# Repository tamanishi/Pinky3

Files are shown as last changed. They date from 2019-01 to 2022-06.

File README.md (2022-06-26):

# Pinky3

> **Warning**  
> If you are using Kicad 6, please see https://github.com/tamanishi/Pinky4/issues/4 .

A split 3 x 7 vertically staggered keys and 4 thumb keys keyboard.  
An idea is inspired from [crkbd](https://github.com/foostan/crkbd), [Lily58](https://github.com/kata0510/Lily58), [Ergo42](https://github.com/Biacco42/Ergo42) and [Helix](https://github.com/MakotoKurauchi/helix).  

product

## Pcb & Plates

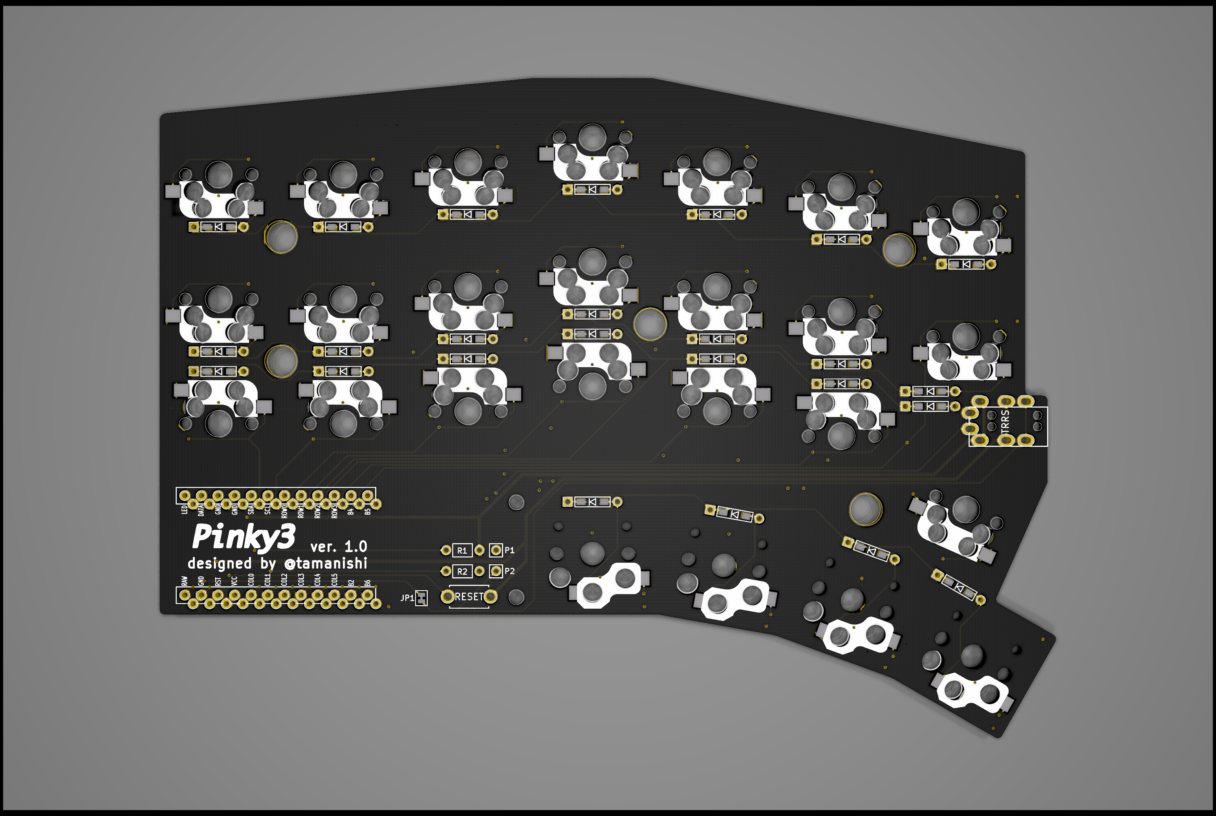
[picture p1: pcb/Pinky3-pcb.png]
pcb

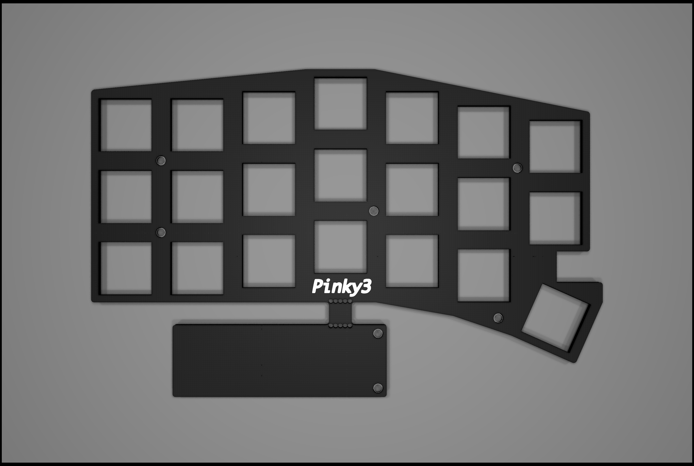
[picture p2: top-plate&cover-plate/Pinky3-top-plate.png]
top plate

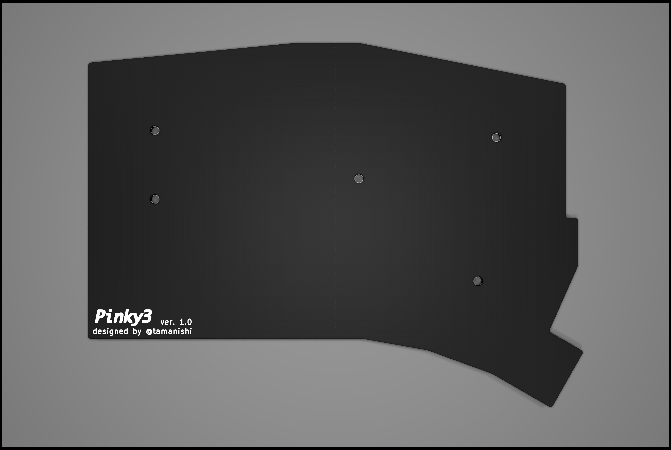
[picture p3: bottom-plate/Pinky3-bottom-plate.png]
bottom plate

<!-- ![plates](plates/Pinky3-plates.png) -->

## Bill of Materials (for both hands)

| # | name | qty |
| ---: | :--- | ---: |
| 1 | pcbs | 2 |
| 2 | top plates | 2 |
| 3 | bottom plates | 2 |
| 4 | Pro Micros | 2 |
| 5 | Conthrough for Pro Micros | 4 |
| 6 | 2 pins tact switches | 2 |
| 7 | TRRS connectors | 2 |
| 8 | diodes (1N4148 or 1N4148W) | 50 |
| 9 | Kailh PCB Sockets (MX Sockets) | 42 |
| 10 | Kailh PCB Sockets (Choc Sockets) | 8 |
| 11 | Cherry MX compatible keyswitches | 42 |
| 12 | Kailh low profile (Choc) keyswitches | 8 |
| 13 | Cherry MX compatible keycaps | 42 |
| 14 | Kailh low profile (Choc) compatible keycaps | 8 |
| 15 | TRS or TRRS cable | 1 |
| 16 | 7mm M2 standoffs (for top and bottom plates) | 10 |
| 17 | 5.5mm M2 standoffs (for Pro Micro cover plates) | 4 |
| 18 | 4mm M2 screws | 28 |
| 19 | rubber cushions | 8 |

## Firmware

See [Quantum Mechanical Keyboard Firmware](https://qmk.fm) and [its Pinky support page](https://github.com/qmk/qmk_firmware/blob/master/keyboards/pinky/readme.md)

## TODOs

- [x] add images (finished product, pcb, plates and parts?)
- [x] add BOM
- [ ] add build log

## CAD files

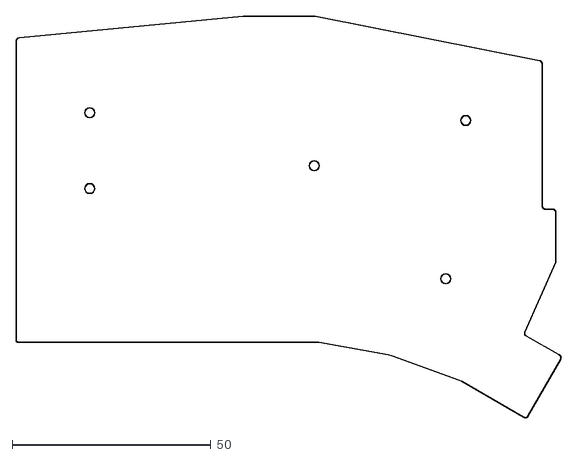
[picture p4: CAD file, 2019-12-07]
bottom-plate-dxf/DXF/Pinky3-bottom-plate-dxf-Edge_Cuts.dxf
137.0 x 100.9

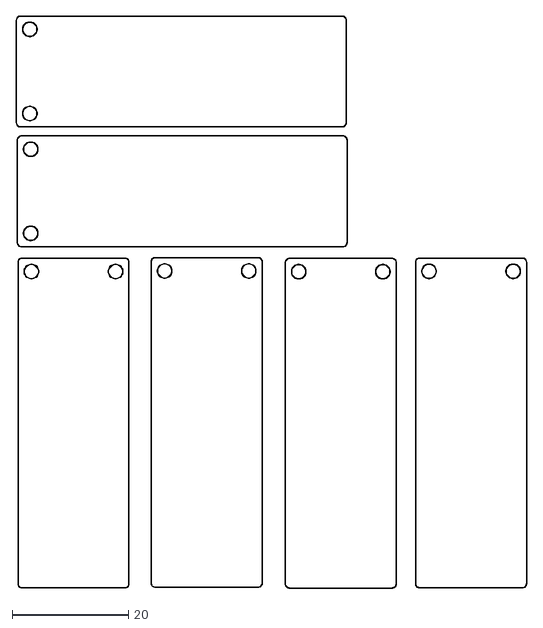
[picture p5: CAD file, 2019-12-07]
cover-plate/DXF/Pinky3-cover-plate-Edge_Cuts.dxf
87.9 x 98.5

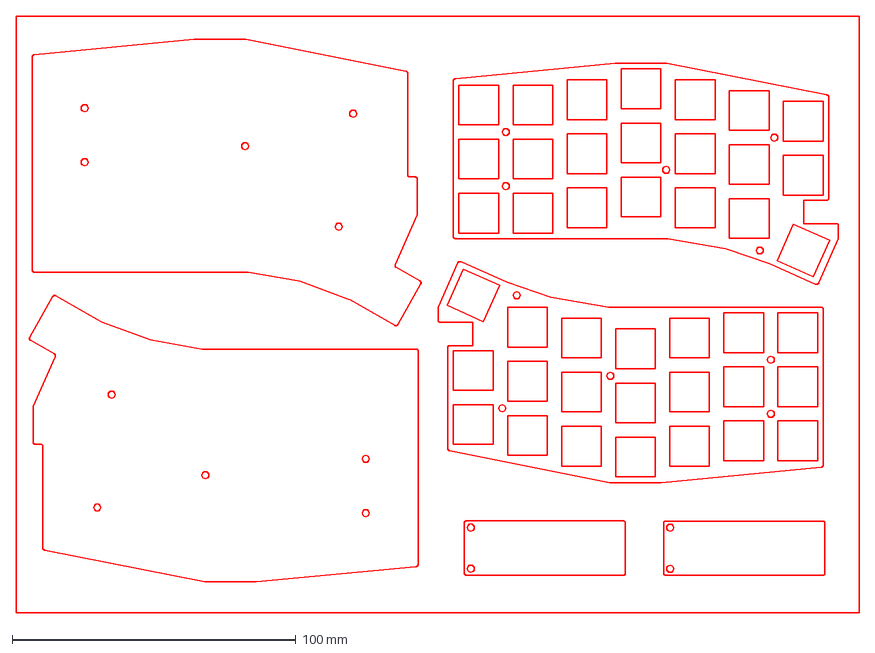
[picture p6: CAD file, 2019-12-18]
plates/DXF/Pinky3_Acrylic_Plates.dxf
297.0 x 210.0 mm

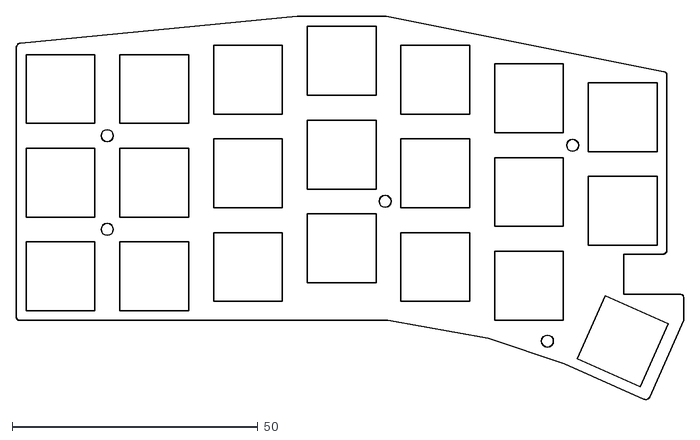
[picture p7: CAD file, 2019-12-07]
top-plate-only-dxf/DXF/Pinky3-top-plate-dxf-Edge_Cuts.dxf
135.7 x 77.9

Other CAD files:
bottom-plate-dxf/DXF/Pinky3-bottom-plate-dxf-Edge_Cuts.dwg
cover-plate/DXF/Pinky3-cover-plate-Edge_Cuts.dwg
plates/DXF/Pinky3_Acrylic_Plates.dwg
top-plate-only-dxf/DXF/Pinky3-top-plate-dxf-Edge_Cuts.dwg

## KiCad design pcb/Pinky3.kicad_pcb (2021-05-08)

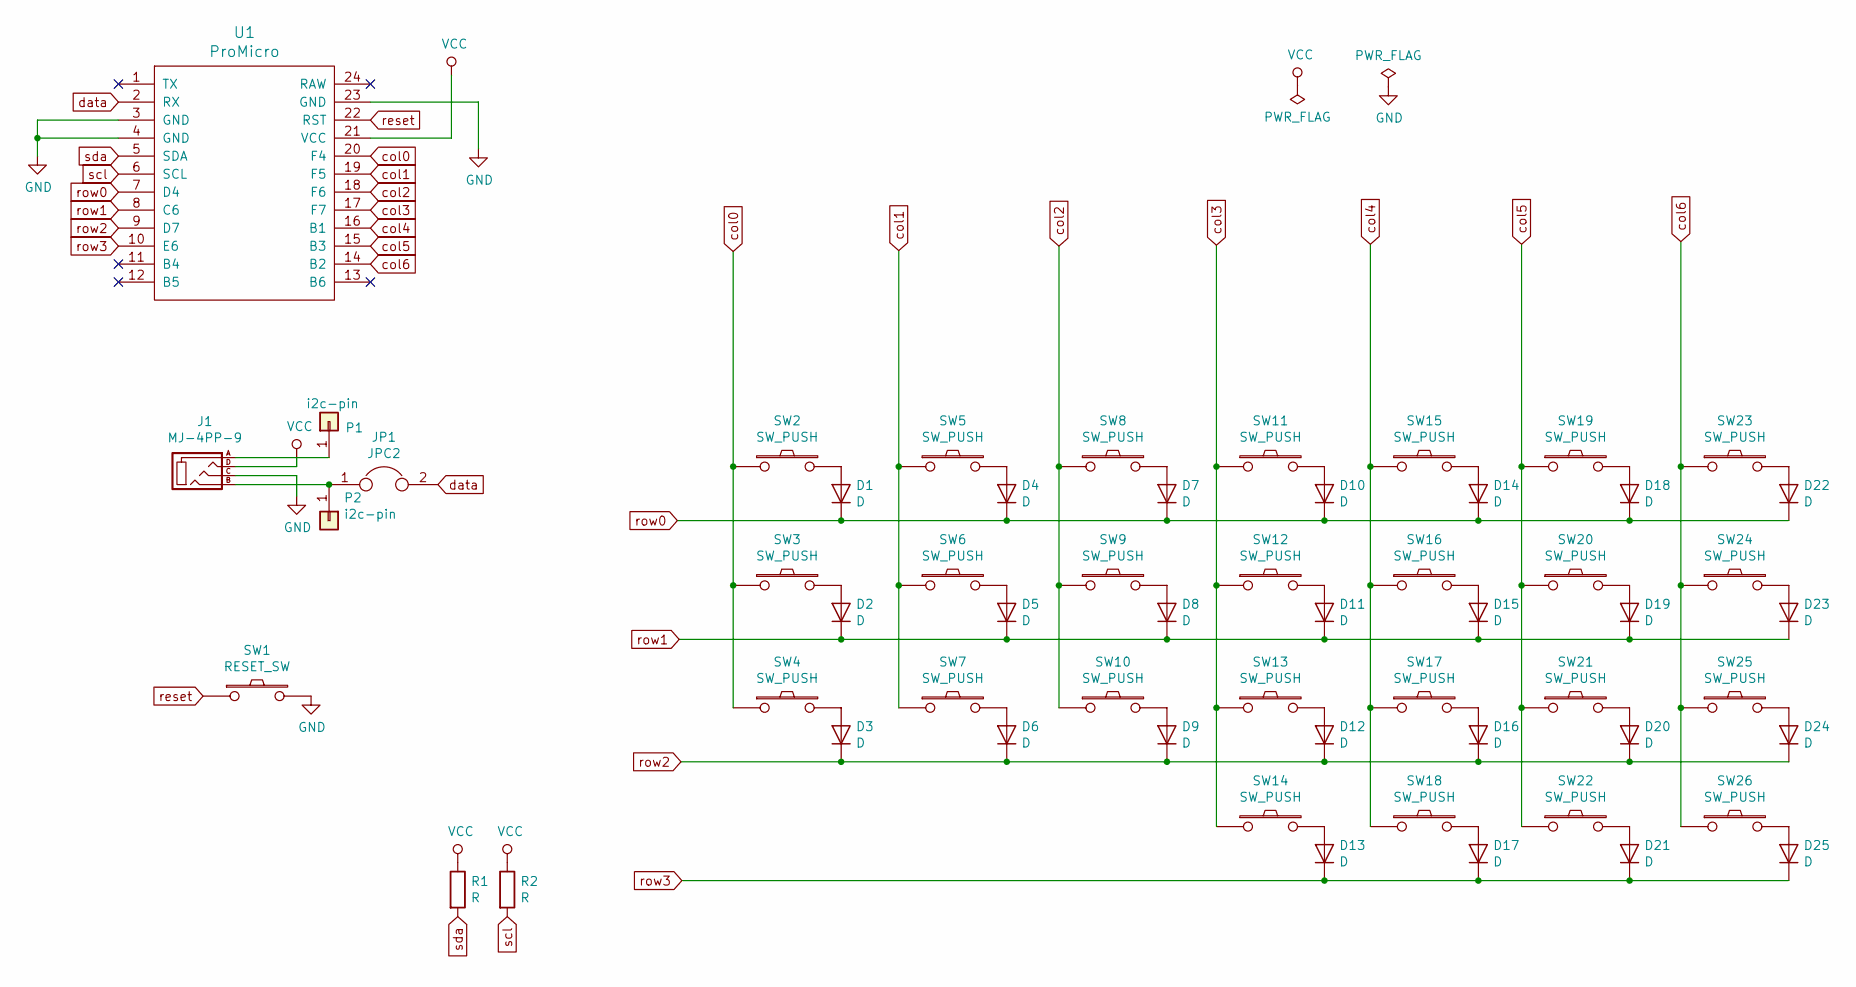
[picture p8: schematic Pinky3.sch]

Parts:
D1, D2, D3, D4, D5, D6, D7, D8, D9, D10, D11, D12, D13, D14, D15, D16, D17, D18, D19, D20, D21, D22, D23, D24, D25: D; D3_TH_SMD
J1: MJ-4PP-9
JP1: JPC2
P1, P2: i2c-pin; 1pin_conn
R1, R2: R
SW1: RESET_SW; ResetSW
SW2, SW3, SW4, SW5, SW6, SW7, SW8, SW9, SW10, SW11, SW12, SW13, SW15, SW16, SW17, SW19, SW20, SW21, SW23, SW24, SW25: SW_PUSH; CherryMX_Hotswap
SW14, SW18, SW22, SW26: SW_PUSH; Choc_Hotswap
U1: ProMicro; ProMicro_v2

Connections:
GND: J1.C, SW1.2, U1.3 (GND), U1.4 (GND), U1.23 (GND)
unnamed: D1.2 (A), SW2.2
unnamed: D2.2 (A), SW3.2
unnamed: D3.2 (A), SW4.2
unnamed: D4.2 (A), SW5.2
unnamed: D5.2 (A), SW6.2
unnamed: D6.2 (A), SW7.2
unnamed: D7.2 (A), SW8.2
unnamed: D8.2 (A), SW9.2
unnamed: D9.2 (A), SW10.2
unnamed: D10.2 (A), SW11.2
unnamed: D11.2 (A), SW12.2
unnamed: D12.2 (A), SW13.2
unnamed: D13.2 (A), SW14.2
unnamed: D14.2 (A), SW15.2
unnamed: D15.2 (A), SW16.2
unnamed: D16.2 (A), SW17.2
unnamed: D17.2 (A), SW18.2
unnamed: D18.2 (A), SW19.2
unnamed: D19.2 (A), SW20.2
unnamed: D20.2 (A), SW21.2
unnamed: D21.2 (A), SW22.2
unnamed: D22.2 (A), SW23.2
unnamed: D23.2 (A), SW24.2
unnamed: D24.2 (A), SW25.2
unnamed: D25.2 (A), SW26.2
unnamed: J1.B, JP1.1, P2.1
col0: SW2.1, SW3.1, SW4.1, U1.20 (F4)
col1: SW5.1, SW6.1, SW7.1, U1.19 (F5)
col2: SW8.1, SW9.1, SW10.1, U1.18 (F6)
col3: SW11.1, SW12.1, SW13.1, SW14.1, U1.17 (F7)
col4: SW15.1, SW16.1, SW17.1, SW18.1, U1.16 (B1)
col5: SW19.1, SW20.1, SW21.1, SW22.1, U1.15 (B3)
col6: SW23.1, SW24.1, SW25.1, SW26.1, U1.14 (B2)
data: JP1.2, U1.2 (RX)
reset: SW1.1, U1.22 (RST)
row0: D1.1 (K), D4.1 (K), D7.1 (K), D10.1 (K), D14.1 (K), D18.1 (K), D22.1 (K), U1.7 (D4)
row1: D2.1 (K), D5.1 (K), D8.1 (K), D11.1 (K), D15.1 (K), D19.1 (K), D23.1 (K), U1.8 (C6)
row2: D3.1 (K), D6.1 (K), D9.1 (K), D12.1 (K), D16.1 (K), D20.1 (K), D24.1 (K), U1.9 (D7)
row3: D13.1 (K), D17.1 (K), D21.1 (K), D25.1 (K), U1.10 (E6)
scl: R2.2, U1.6 (SCL)
sda: R1.2, U1.5 (SDA)

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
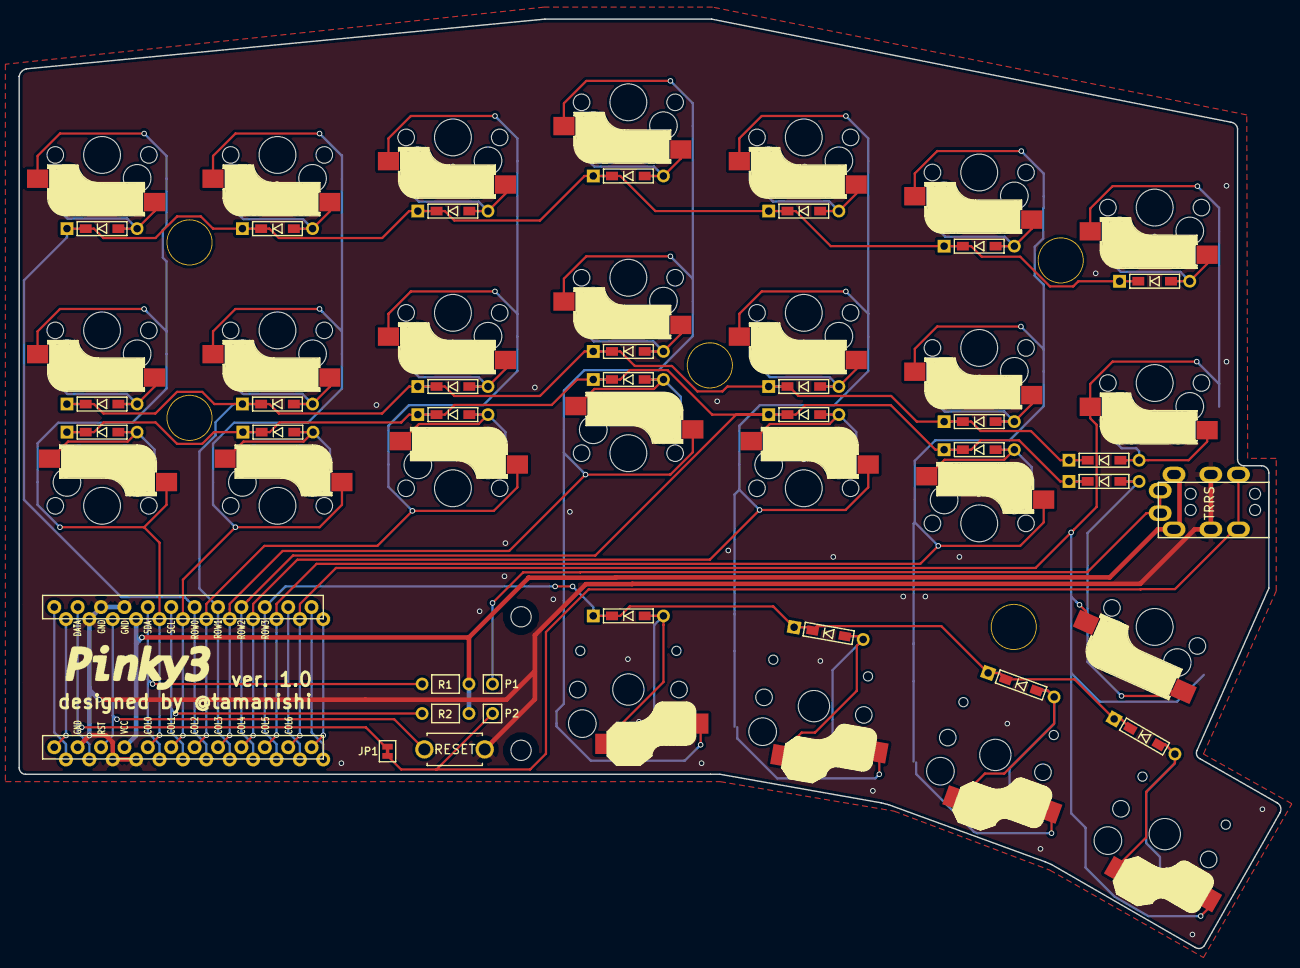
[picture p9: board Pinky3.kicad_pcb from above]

Board: 2 copper layers, 137.0 x 100.9 mm, 65 parts (0 on the bottom side), 44 nets.

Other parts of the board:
HOLE_M2, HOLE_M2#2: VAL**; HOLE_M2
Ref**: Val**; HOLE
Ref**#2, Ref**#3, Ref**#4, Ref**#5: Val**; HOLE

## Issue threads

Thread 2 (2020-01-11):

[question] What are JP1, R1, R2, P1, and P2 for?

repercussion, 2020-01-11:
JP1 - What is this jumper for?

R1 and R2 - I assume these are for resistors for underglow?

P1 and P2 - Haven't the foggiest.

tamanishi, 2020-01-14:
[image: reset_switch.jpg]
Hi.

Sorry for the late reply.

> I've bought a few PCBs and necessary parts, but I'm wondering if you
might help me find the appropriate resest switches.

I'm using reset switch like this. (see attached.

> JP1 - What is this jumper for?

> R1 and R2 - I assume these are for resistors for underglow?

> P1 and P2 - Haven't the foggiest.
JP1 is for switching the communication protocol for left and right between
I2C or serial.
If JP1 is closed, the communication is on serial protocol.
If JP1 is opened, the communication is on I2C protocol.
and R1, R2, P1 and P2 are for I2C protocol.
But I don't test I2C protocol physically yet.

Serial protocol is OK for me for now.

I hope this helps you.

--
Masayuki Sunahara

On Sun, Jan 12, 2020 at 5:02 AM repercussion <notifications@github.com>
wrote:

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

repercussion, 2020-01-15:
Thank you very much for the information!

The image of the reset switch didn't make it from attachment to GitHub.

tamanishi, 2020-01-15:
Oops.

please try this.

https://imgur.com/gallery/vSJpcNz

--
Masayuki Sunahara

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

repercussion, 2020-01-21:
Thanks!

[Reset switch](https://i.imgur.com/EkxfLI0.jpg)

Closed 2020-02-08.

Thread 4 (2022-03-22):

Thumb keys compatible with MX sockets/switches?

jwhendy, 2022-03-22:
*Probably* a dumb question (all the pictures show choc), but has been [asked before](https://www.reddit.com/r/olkb/comments/kyrnhe/pinky34_thumb_keys_kailh_choc_only_or_mx_as_well/) so I figured I'd get the definitive answer :)

Does one have to use choc switches for the thumb keys, or could MX (direct solder or sockets) work as well?

lierdakil, 2022-07-07:
Bottom row hole positions and sizes are not compatible with cherry-style switches. If you're going to order the pcbs custom-made, you could tweak the schematic. It wouldn't be very comfortable, though, as all keys would end up being the same height.

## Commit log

2019-01-06 - add images - add logo - change thumb keys footprints to choc only
    [Pinky3-bottom-plate.kicad_pcb, Pinky3-top-plate.kicad_pcb, Pinky3.kicad_pcb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]
2019-01-14 add BOM
2019-01-14 - join plates - tweak README
    [Pinky3-bottom-plate.kicad_pcb, Pinky3-plates.kicad_pcb]
2019-01-15 remove joined plate
    [Pinky3-plates.kicad_pcb]
2019-08-16 add top plate only project
    [Pinky3-top-plate.kicad_pcb]
2019-10-06 tweak silk
    [Pinky3.kicad_pcb]
2019-12-07 add plates dxf.
    [Pinky3-bottom-plate-dxf-Edge_Cuts.dwg, Pinky3-bottom-plate-dxf-Edge_Cuts.dxf, Pinky3-bottom-plate-dxf.kicad_pcb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]
2019-12-18 add plate DXF
    [Pinky3_Acrylic_Plates.dwg, Pinky3_Acrylic_Plates.dxf]
2020-02-24 add Horizontal Reset Switch
2020-07-27 tweak standoff length for cover plates
